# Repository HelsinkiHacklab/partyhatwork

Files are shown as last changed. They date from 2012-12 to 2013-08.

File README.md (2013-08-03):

partyhatwork
============

Mesh network of [party][party1]-[hats][hat1], see http://kirjoitusalusta.fi/hacklab-partyhatwork

[party1]: http://www.youtube.com/watch?v=EIru0xmfsWs
[hat1]: http://www.flickr.com/photos/netlcom/7639700776/in/pool-hlt

## Hardware

  * [rev1](./hardware/board_rev1/)

## Software

  * Reference XMegaduino [sketch](./software/arduino/partyhatwork/)
  * [Instructions](https://github.com/HelsinkiHacklab/XMega-boards/tree/master/software/arduino-xmega) for patching XMegaduino to support our board variant
  * [XBee API wrapper](./software/pc/beehive)
  * [Animation builder](http://helsinkihacklab.github.io/partyhatwork/software/pc/animationbuilder/animationbuilder.html)

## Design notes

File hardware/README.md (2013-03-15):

# Hardware

See directories for details, current board revision is [rev1](./board_rev1/).

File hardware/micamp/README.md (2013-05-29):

# Microphone board

Basically this [sparkfun board][sparkmic] but with better mic and suitably adjusted filter values.

[sparkmic]: https://www.sparkfun.com/products/9964

## BOM

  - http://www.digikey.fi/product-detail/en/CMA-4544PF-W/102-1721-ND/1869981
  - http://www.digikey.fi/product-detail/en/OPA344NA%2F250/OPA344NACT-ND/362263
  - Some standard 0603 size caps & resistors which I will enumerate later

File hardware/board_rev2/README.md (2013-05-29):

# Rev2 board

## TODO

  * Design it, remembering to fix bugs of rev1
  * Decide on on/off solution, heavily leaning towards: [LTC2954](http://www.digikey.fi/product-detail/en/LTC2954CTS8-2%23TRMPBF/LTC2954CTS8-2%23TRMPBFCT-ND/1232682) with [SI4465ADY](http://www.digikey.fi/product-detail/en/SI4465ADY-T1-E3/SI4465ADY-T1-E3CT-ND/1656942)
  * Doublecheck that the 3.3V reg on the XMega board will not throw a hissy fit if  we provide 3.3V from the partyboard (with and without 5V to xmega board provided)
    * In any case [MCP1826T](http://www.digikey.fi/product-detail/en/MCP1826T-3302E%2FDC/MCP1826T-3302E%2FDCCT-ND/1776943) looks like a good choice for regulator (very low drop even at high current) and decent price.
  * Consider MCP73837 as alternative LiPo charger
    * See http://ww1.microchip.com/downloads/en/AppNotes/01149c.pdf
  * Consider adding a [microphone](../micamp/) (for sound-sensitive stuff)
    * or at least a standard header for connecting that board...

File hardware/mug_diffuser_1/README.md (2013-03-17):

# Diffuser for 2 leds based on a plastic mug

## BOM

  * Orthex juomamuki 4dl, EAN: 6411760154911. This particular mug is likely only available in Finland (At least Prisma carries it)
  * Thin aluminium sheet with smooth surface, 155mmx160mm minimum. Bauhaus & K-rauta have these small & thin sheets in various sizes and finishes.

## Instructions

  1. Print the [template](./reflector_template.svg)
  2. Attach it to your alu sheet (glue is ok)
  3. Use tin snips to cut out the two shapes, you can ignore the two small notches
  4. Make a 90-degree bend on the line indicated by the notches. To save yourself the trouble of 
     detaching the template paper, make it so that the paper sides go back-to-back when you have two reflectors.

If you have some sort of CNC that can cut thin metal sheets you can use the [DXF-file](./reflector.dxf).

Some photos: [template][1], [cut & bent][2], [glued][3] & [in use][4]

[1]: https://picasaweb.google.com/lh/photo/nGylbYth7qOaIvtZZEVNvtMTjNZETYmyPJy0liipFm0?feat=directlink
[2]: https://picasaweb.google.com/lh/photo/HIvYXgTCgEQDVCX9EG3fN9MTjNZETYmyPJy0liipFm0?feat=directlink
[3]: https://picasaweb.google.com/lh/photo/DAcRxKpaTQmPHOa6ay1VA9MTjNZETYmyPJy0liipFm0?feat=directlink
[4]: https://picasaweb.google.com/lh/photo/euiXRlEUV-68nEd8NDOWBtMTjNZETYmyPJy0liipFm0?feat=directlink

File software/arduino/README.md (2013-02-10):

# Arduino (well, XMegaduino) software

## partyhatwork

This is the reference implementation of a PartyHatWork node. It implements only the base protocol, if you wish
to extend the protocol or redefine behaviours do not change this sketch but create a new copy. Variants that are deemed
common/good/crazy enough can be added here as separate sketches.

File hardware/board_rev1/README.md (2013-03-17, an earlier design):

# Revision1 board

The current board is designed to be a "shield" to the Xmega32A4U 
breakout board from https://github.com/HelsinkiHacklab/XMega-boards 

Essential pins are pre-connected to modules and drivers, rest of the spare pins (both XMega
and XBee) will be brought out to IDC connectors for further use.

## BOM

  * 1 https://github.com/HelsinkiHacklab/XMega-boards/blob/master/XmegaA4U_v1.jpg (v2 is perfectly fine as well)
    * Flash with [atxmega32a4u_104_PD5.hex](xmegabootloaders/atxmega32a4u_104_PD5.hex) to use PD5 to activate DFU.
      * Convert hex to bin for avrdude: `avr-objcopy -I ihex -O binary atxmega32a4u_104_PD5.hex atxmega32a4u_104_PD5.bin`
      * program with AVRISPmkII: `avrdude -e -c avrisp2 -P usb -p x32a4 -U boot:w:atxmega32a4u_104_PD5.bin`
  * 3 Dual- N-Channel MOSFETs http://fi.rsdelivers.com/product/vishay/si1912edh-t1-e3/mosfet-n-channel-20v-113a-sc-70-6/7103235.aspx
  * 1 XBee (Series 2)
  * 2 1x10 2.0mm female header (for XBee) http://fi.rsdelivers.com/product/harwin/m22-7131042/10w-sil-vertical-pcb-skt/6058796.aspx | http://www.digikey.fi/product-detail/en/M22-7131042/952-1354-5-ND/2264335?cur=USD
  * 2 1x16 2.54mm female header (for XMega) http://fi.rsdelivers.com/product/te-connectivity/1-215297-6/16-way-single-row-vertical-gold-skt/5092880.aspx
  * 1 2x3 2.54mm female header (ISP stacking) http://fi.rsdelivers.com/product/rs/w3482106trc/3-way-2-row-top-entry-socket-01in-pitch/2518216.aspx
  * 1 1x3 2.54mm female header (XMega power connector stacking) http://fi.rsdelivers.com/product/rs/w3481103trc/3way-1-row-top-entry-socket-254mm-pitch/2518187.aspx
  * 1 SOT-223 packaged LDO 3.3V regulator (optional but high-powered one is recommended). **Doublecheck the pinout**: this one is GND-Vout-Vin (LM1117 pinout).
    * This looks like a good choice: http://www.digikey.fi/product-detail/en/ADP3338AKCZ-3.3RL7/ADP3338AKCZ-3.3RL7CT-ND/820438
  * 1 MCP73831T LiPo charge controller http://fi.rsdelivers.com/product/microchip/mcp73831t-2dci-ot/charge-controller-li-ion-li-pol/7240599.aspx
  * 1 JST battery connector http://fi.rsdelivers.com/product/jst/s2b-ph-sm4-tblfsn/ph-smt-side-entry-shroud-header-2-way/6881353.aspx | http://www.digikey.fi/product-detail/en/S2B-PH-SM4-TB%28LF%29%28SN%29/455-1749-1-ND/926846?cur=USD
  * 1 LiPo battery with JST-connector https://www.sparkfun.com/products/8483 or https://www.sparkfun.com/products/8484
  * 1 2x6 2.54mm pin header -right angle
  * 2 2x8 2.54mm pin header -right angle (the other one can alternatively be straight)
  * 2 0805 4.7uF SMD caps
  * 1 0603 SMD led (charge indicator)
  * 1 0603 300r SMD resistor (for charge indicator, adjust value for your LED)
  * 1 0603 2.8k SMD resistor
  * 1 0603 10k SMD resistor
  * 1 0603 50k SMD resistor
  * 1 0603 100k SMD resistor
  * 6 0805 SMD resistors, values based on your desired LED currents
  * 1 0603 0.1uF SMD cap
  * 1 1210 SMD cap (size for your LEDs), 0805 cap should still be solderable too

## Bugs

  * No on/off control for battery power (apart from disconnecting alltotger)
  * without the "optional" regulator battery cannot power the XMega board
    (you could also jumper VBAT to VUSB but that will cause trouble when you connect the USB cable)
  * The 3.3V regulator has weird pinout (whyever eagle has more parts with that one than with the logical and actually more easily available one beats me)
  * The LiPo charge current control resistor pads form a square, making it easy to accidentally place resistors in wrong orientation.

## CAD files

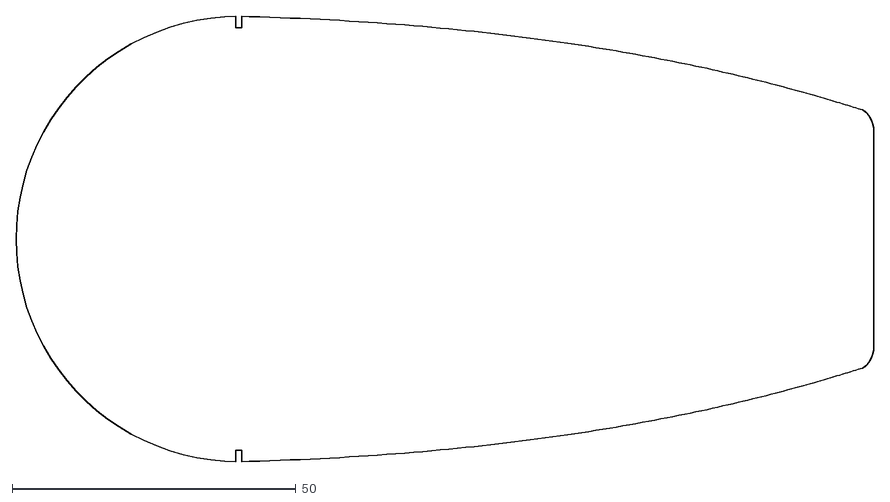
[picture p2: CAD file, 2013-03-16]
hardware/mug_diffuser_1/reflector.dxf
151.2 x 78.5

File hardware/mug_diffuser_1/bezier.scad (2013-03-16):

//=====================================
// This is public Domain Code
// Contributed by: William A Adams
//
// This is from http://www.thingiverse.com/thing:8454
// See also: http://williamaadams.wordpress.com/2011/05/12/mr-bezier-goes-to-openscad/
//=====================================
joinfactor = 0.125;

gSteps = 100;
gHeight = 4;

//======================================
// Demos
//======================================
//BezCubicFilletColored( [[0, 15],[5,5],[10,5],[15,15]], [7.5,12], gSteps, gHeight, 
//	[[1,0,0],[1,1,0],[0,1,1],[0,0,1]]);
//BezCubicFilletColored( [[0, 15],[5,5],[10,5],[15,15]], [7.5,18], gSteps, gHeight, 
//	[[1,0,0],[0,1,0],[0,1,0],[0,0,1]]);
//DrawCubicControlPoints([[0, 15],[5,5],[10,5],[15,15]], [7.5,18], gHeight, $fn=12);

//BezCubicFillet( [[0, 5],[5,15],[10,3],[15,10]], [7.5,0], gSteps, gHeight);
//DrawCubicControlPoints( [[0, 5],[5,15],[10,3],[15,10]], [7.5,0], gHeight, $fn=12);

//BezCubicRibbon([[0,15],[6,13],[3,5],[15,0]], [[0,13],[6,11],[3,2],[13,0]]);

//=======================================
// Functions
// These are the 4 blending functions for a cubic bezier curve
//=======================================
// Bernstein Polynomials
function BEZ03(u) = pow((1-u), 3);
function BEZ13(u) = 3*u*(pow((1-u),2));
function BEZ23(u) = 3*(pow(u,2))*(1-u);
function BEZ33(u) = pow(u,3);

// Calculate a singe point along a cubic bezier curve
function PointOnBezCubic2D(p0, p1, p2, p3, u) = [
	BEZ03(u)*p0[0]+BEZ13(u)*p1[0]+BEZ23(u)*p2[0]+BEZ33(u)*p3[0],
	BEZ03(u)*p0[1]+BEZ13(u)*p1[1]+BEZ23(u)*p2[1]+BEZ33(u)*p3[1]];

function PointOnBezCubic3D(p0, p1, p2, p3, u) = [
	BEZ03(u)*p0[0]+BEZ13(u)*p1[0]+BEZ23(u)*p2[0]+BEZ33(u)*p3[0],
	BEZ03(u)*p0[1]+BEZ13(u)*p1[1]+BEZ23(u)*p2[1]+BEZ33(u)*p3[1],
	BEZ03(u)*p0[2]+BEZ13(u)*p1[2]+BEZ23(u)*p2[2]+BEZ33(u)*p3[2]];

//=======================================
// Modules
//=======================================
// This function will extrude a bezier solid from a bezier curve
// It is a straight up prism
// c - ControlPoints
//
module BezCubicFillet(c, focalPoint, steps=gSteps, height=gHeight)
{
	for(step = [steps:1])
	{
		linear_extrude(height = height, convexity = 10) 
		polygon(
			points=[
				focalPoint,
				PointOnBezCubic2D(c[0], c[1], c[2],c[3], step/steps),
				PointOnBezCubic2D(c[0], c[1], c[2],c[3], (step-1)/steps)],
			paths=[[0,1,2,0]]
		);
	}
}

module BezCubicFilletColored(c, focalPoint, steps=gSteps, height=gHeight, colors)
{
	for(step = [steps:1])
	{
		color(PointOnBezCubic3D(colors[0], colors[1], colors[2], colors[3], step/steps))
		linear_extrude(height = height, convexity = 10) 
		polygon(
			points=[
				focalPoint,
				PointOnBezCubic2D(c[0], c[1], c[2],c[3], step/steps),
				PointOnBezCubic2D(c[0], c[1], c[2],c[3], (step-1)/steps)],
			paths=[[0,1,2,0]]
		);
	}
}


module BezCubicRibbon(c1, c2, steps=gSteps, height=gHeight, colors=[[1,0,0],[1,1,0],[0,1,1],[0,0,1]])
{
	for (step=[0:steps-1])
	{
		color(PointOnBezCubic3D(colors[0], colors[1], colors[2], colors[3], step/steps))
		linear_extrude(height = height, convexity = 10) 
		polygon(
			points=[
				PointOnBezCubic2D(c1[0], c1[1], c1[2],c1[3], step/steps),
				PointOnBezCubic2D(c2[0], c2[1], c2[2],c2[3], (step)/steps),
				PointOnBezCubic2D(c2[0], c2[1], c2[2],c2[3], (step+1)/steps),
				PointOnBezCubic2D(c1[0], c1[1], c1[2],c1[3], (step+1)/steps)],
			paths=[[0,1,2,3]]
		);

	}
}

//==============================================
// Test functions
//
// These test functions help demonstrate that the core blending
// functions actually work correctly.
//==============================================
//PlotBEZ0(100);
//PlotBEZ1(100);
//PlotBEZ2(100);
//PlotBEZ3(100);
//PlotBez4Blending();

module DrawCubicControlPoints(c, focalPoint, height)
{
	// Draw control points
	// Start point
	translate(c[0])
	color([1,0,0])
	cylinder(r=0.5, h=height+joinfactor);

	// Controll point 1
	translate(c[1])
	color([0,0,0])
	cylinder(r=0.5, h=height+joinfactor);

	// Control point 2
	translate(c[2])
	color([0,0,0])
	cylinder(r=0.5, h=height+joinfactor);

	// End Point
	translate(c[3])
	color([0,0,1])
	cylinder(r=0.5, h=height+joinfactor);


	// Draw the focal point
	translate(focalPoint)
	color([0,1,0])
	cylinder(r=0.5, h=height+joinfactor);
}

module PlotBEZ0(steps)
{
	cubeSize = 1;
	cubeHeight = steps;

	for (step=[0:steps])
	{
		translate([cubeSize*step, 0, 0])
		cube(size=[cubeSize, cubeSize, BEZ03(step/steps)*cubeHeight]);
	}	
}

module PlotBEZ1(steps)
{
	cubeSize = 1;
	cubeHeight = steps;

	for (step=[0:steps])
	{
		translate([cubeSize*step, 0, 0])
		cube(size=[cubeSize, cubeSize, BEZ13(step/steps)*cubeHeight]);
	}	
}

module PlotBEZ2(steps)
{
	cubeSize = 1;
	cubeHeight = steps;

	for (step=[0:steps])
	{
		translate([cubeSize*step, 0, 0])
		cube(size=[cubeSize, cubeSize, BEZ23(step/steps)*cubeHeight]);
	}	
}

module PlotBEZ3(steps)
{
	cubeSize = 1;
	cubeHeight = steps;

	for (step=[0:steps])
	{
		translate([cubeSize*step, 0, 0])
		cube(size=[cubeSize, cubeSize, BEZ33(step/steps)*cubeHeight]);
	}	
}

module PlotBez4Blending()
{
	sizing = 100;

	translate([0, 0, sizing + 10])
	PlotBEZ0(100);

	translate([sizing+10, 0, sizing + 10])
	PlotBEZ1(100);

	translate([0, 0, 0])
	PlotBEZ2(100);

	translate([sizing+10, 0, 0])
	PlotBEZ3(100);
}

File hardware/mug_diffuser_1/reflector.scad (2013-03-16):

// This is from http://www.thingiverse.com/thing:8454
// See also: http://williamaadams.wordpress.com/2011/05/12/mr-bezier-goes-to-openscad/
include <bezier.scad>

measured_points = [
    [0, 79.0/2], // x,y (mug sideways, opening to left, tracking *inside* dimensions)
    [110, 46.0/2],
    [110.0/2, 71.0/2],
    [110.0/4, 75.0/2],
    [110.0/4*3, 60.0/2],
];

/**
 * The fitted control points from curve_fitting.py
 *
    (62, 38), # P1
    (97, 27), # P2
 */
/**
 * This is the main shape of half a mug, lacking the steep curve at the very bottom
 */
module half_mug_maincurve()
{
    // Calculate and cache results, will speed up rendering especially when modifying other parameters.
    render()
    {
        union()
        {
            BezCubicFillet([measured_points[0], [62, 38], [97, 27], measured_points[1] ], [0,0]);
            cube([measured_points[1][0], measured_points[1][1], gHeight], center = false);
        }
    }
}
/**
 * Half a mug
 */
bottomcube_xy = [measured_points[1][0]+2, measured_points[1][1]-4];
module half_mug()
{
    $fn=100;
    // Calculate and cache results, will speed up rendering especially when modifying other parameters.
    render()
    {
        union()
        {
            half_mug_maincurve();
            // Cube indicating full depth
            cube([bottomcube_xy[0], bottomcube_xy[1] , gHeight], center = false);
            // Bezier merging the end of the main curve to the bottom cube
            BezCubicFillet([measured_points[1], [bottomcube_xy[0]-1, bottomcube_xy[1]+3.5], [bottomcube_xy[0]+0, bottomcube_xy[1]+2], bottomcube_xy ], [measured_points[1][0]-6,measured_points[1][1]-6]);
        }
    }
}

//half_mug();

module reflector()
{
    $fn=100;
    difference()
    {
        union()
        {
            // Two mug halves mirrored
            half_mug();
            translate([0,0.5,0])
            {
                mirror([0,1,0])
                {
                    half_mug();
                }
            }
            // The semicircle that will be bent 90degrees to form the bottom of the reflector
            translate([0,0.25,0])
            {
                cylinder(r=measured_points[0][1]-0.25, h=gHeight);
            }
        }
        // Two small notches to indicate the bend-line
        translate([-0.5, measured_points[0][1]-2, -0.5])
        {
            cube([1, 2.5, gHeight+1], center = false);
        }
        translate([-0.5, (-1*measured_points[0][1]), -0.5])
        {
            cube([1, 2.5, gHeight+1], center = false);
        }
    }
}

module reflector_2d()
{
    projection(cut=false)
    {
        reflector();
    }
}

// Output the shape
//reflector();
reflector_2d();

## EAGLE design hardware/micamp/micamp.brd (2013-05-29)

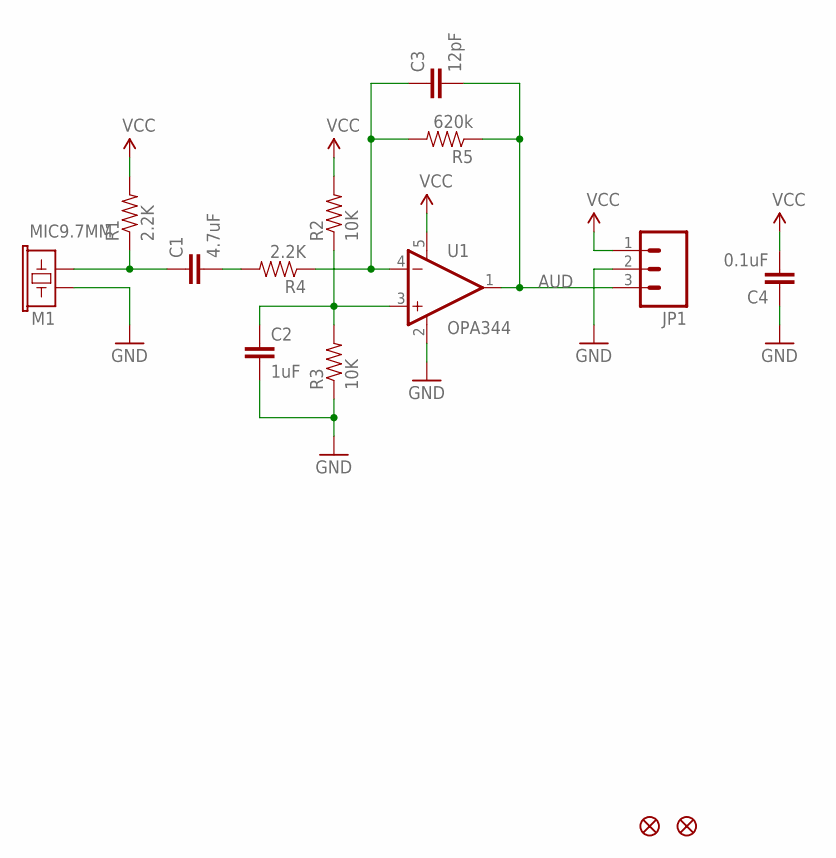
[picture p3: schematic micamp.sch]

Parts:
C1: 4.7uF; 0603-CAP
C2: 1uF; 0603-CAP
C3: 12pF; 0603-CAP
C4: 0.1uF; 0603-CAP
JP1: M03PTH; 1X03
JP2, JP3: FIDUCIAL1X2; FIDUCIAL-1X2
M1: MIC9.7MM; MIC-9.7MM
R1, R4: 2.2K; 0603-RES
R2, R3: 10K; 0603-RES
R5: 620k; 0603-RES
U1: OPA344; SOT23-5

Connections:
AUD: C3.2, JP1.3, R5.1, U1.1 (OUT)
GND: C2.2, C4.1, JP1.2, M1.2, R3.1, U1.2 (V-)
unnamed: C1.1, M1.1, R1.1
unnamed: C3.1, R4.1, R5.2, U1.4 (-IN)
unnamed: C1.2, R4.2
unnamed: C2.1, R2.1, R3.2, U1.3 (+IN)
VCC: C4.2, JP1.1, R1.2, R2.2, U1.5 (V+)

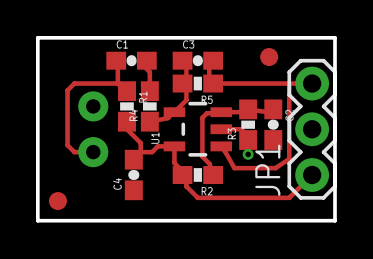
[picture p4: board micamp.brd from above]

Board: 2 copper layers, 16.5 x 10.2 mm, 14 parts (1 on the bottom side), 7 nets.

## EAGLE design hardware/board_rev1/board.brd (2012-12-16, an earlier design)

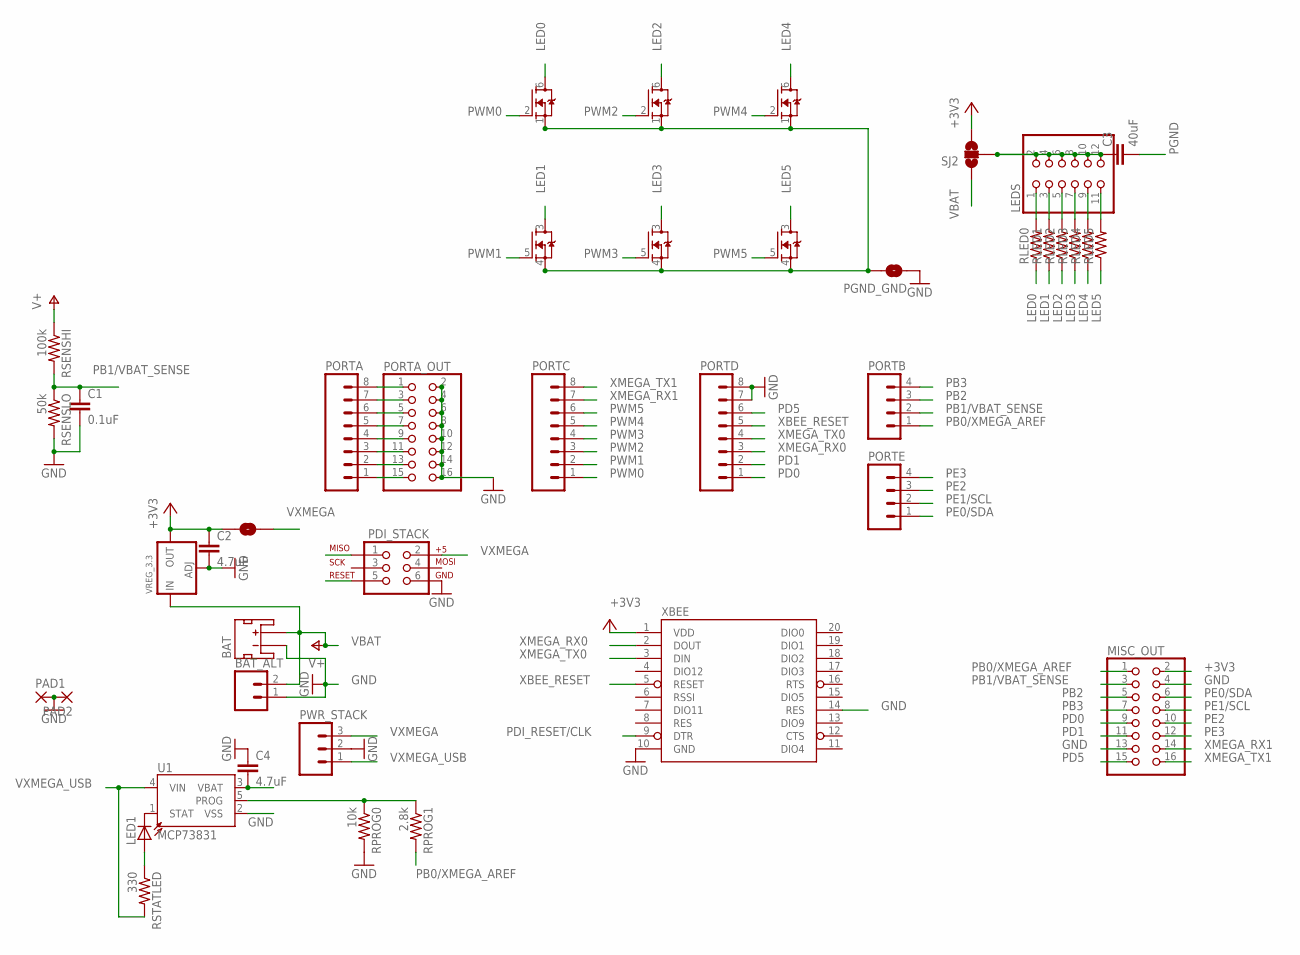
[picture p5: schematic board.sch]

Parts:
+3.3V_VXMEGA: SOLDERJUMPERTRACE; SJ_2S-TRACE
BAT: JST_2MM_MALE; JST-2-SMD
BAT_ALT: M02PTH; 1X02
C1: 0.1uF; C0603K
C2: 4.7uF; C0805K
C3: 40uF; C1210
C4: 4.7uF; C0805
DRV0, DRV1, DRV2: MOSFET-N_DUAL; SOT363
LED1: LEDCHIP-LED0603; CHIP-LED0603
LEDS: PINHD-2X6/90; 2X06/90
MISC_OUT: PINHD-2X8/90; 2X08/90
PAD1, PAD2: 3,81/1,4
PDI_STACK: AVR_SPI_PRG_6NS; 2X3-NS
PGND_GND: SOLDERJUMPERTRACE; SJ_2S-TRACE
PORTA: M081X08; 1X08
PORTA_OUT: PINHD-2X8; 2X08
PORTB: M04PTH; 1X04
PORTC: M081X08; 1X08
PORTD: M081X08; 1X08
PORTE: M04PTH; 1X04
PWR_STACK: M03PTH; 1X03
RLED0, RLED1, RLED2, RLED3, RLED4, RLED5: R-US_R0805; R0805
RPROG0: 10k; R0603
RPROG1: 2.8k; R0603
RSENSHI: 100k; R0603
RSENSLO: 50k; R0603
RSTATLED: 330; R0603
SJ2: SOLDERJUMPER_2WAY-OLDT; SJ_2
U1: MCP73831; SOT23-5
VREG_3.3: LM1117SOT223-WAVE; SOT223-W
XBEE: XBEE-1B2; XBEE-SILK

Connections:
+3V3: +3.3V_VXMEGA.1, C2.1, MISC_OUT.2, SJ2.3, VREG_3.3.2 (OUT), XBEE.1 (VDD)
GND: BAT.1 (-), BAT_ALT.1, C1.2, C2.2, C4.1, MISC_OUT.4, MISC_OUT.13, PAD1.1, PAD2.1, PDI_STACK.6, PGND_GND.1, PORTA_OUT.2, PORTA_OUT.4, PORTA_OUT.6, PORTA_OUT.8, PORTA_OUT.10, PORTA_OUT.12, PORTA_OUT.14, PORTA_OUT.16, PORTD.7, PORTD.8, PWR_STACK.2, RPROG0.2, RSENSLO.2, U1.2 (VSS), VREG_3.3.1 (ADJ), XBEE.10 (GND), XBEE.14 (RES)
LED0: DRV0.6 (D), RLED0.1
LED0R: LEDS.1, RLED0.2
LED1: DRV0.3 (D), RLED1.1
LED1R: LEDS.3, RLED1.2
LED2: DRV1.6 (D), RLED2.1
LED2R: LEDS.5, RLED2.2
LED3: DRV1.3 (D), RLED3.1
LED3R: LEDS.7, RLED3.2
LED4: DRV2.6 (D), RLED4.1
LED4R: LEDS.9, RLED4.2
LED5: DRV2.3 (D), RLED5.1
LED5R: LEDS.11, RLED5.2
unnamed: LED1.C, U1.1 (STAT)
unnamed: LED1.A, RSTATLED.1
PA0: PORTA.1, PORTA_OUT.15
PA1: PORTA.2, PORTA_OUT.13
PA2: PORTA.3, PORTA_OUT.11
PA3: PORTA.4, PORTA_OUT.9
PA4: PORTA.5, PORTA_OUT.7
PA5: PORTA.6, PORTA_OUT.5
PA6: PORTA.7, PORTA_OUT.3
PA7: PORTA.8, PORTA_OUT.1
PB0/XMEGA_AREF: MISC_OUT.1, PORTB.1, RPROG1.2
PB1/VBAT_SENSE: C1.1, MISC_OUT.3, PORTB.2, RSENSHI.2, RSENSLO.1
PB2: MISC_OUT.5, PORTB.3
PB3: MISC_OUT.7, PORTB.4
PD0: MISC_OUT.9, PORTD.1
PD1: MISC_OUT.11, PORTD.2
PD5: MISC_OUT.15, PORTD.6
PDI_DATA: PDI_STACK.1
PDI_RESET/CLK: PDI_STACK.5, XBEE.9 (DTR)
PE0/SDA: MISC_OUT.6, PORTE.1
PE1/SCL: MISC_OUT.8, PORTE.2
PE2: MISC_OUT.10, PORTE.3
PE3: MISC_OUT.12, PORTE.4
PGND: C3.2, DRV0.1 (S), DRV0.4 (S), DRV1.1 (S), DRV1.4 (S), DRV2.1 (S), DRV2.4 (S), PGND_GND.2
PWM0: DRV0.2 (G), PORTC.1
PWM1: DRV0.5 (G), PORTC.2
PWM2: DRV1.2 (G), PORTC.3
PWM3: DRV1.5 (G), PORTC.4
PWM4: DRV2.2 (G), PORTC.5
PWM5: DRV2.5 (G), PORTC.6
RPROG: RPROG0.1, RPROG1.1, U1.5 (PROG)
VBAT: BAT.2 (+), BAT_ALT.2, C4.2, RSENSHI.1, SJ2.1, U1.3 (VBAT), VREG_3.3.3 (IN)
VLED: C3.1, LEDS.2, LEDS.4, LEDS.6, LEDS.8, LEDS.10, LEDS.12, SJ2.2
VXMEGA: +3.3V_VXMEGA.2, PDI_STACK.2, PWR_STACK.3
VXMEGA_USB: PWR_STACK.1, RSTATLED.2, U1.4 (VIN)
XBEE_RESET: PORTD.5, XBEE.5 (RESET)
XMEGA_RX0: PORTD.3, XBEE.2 (DOUT)
XMEGA_RX1: MISC_OUT.14, PORTC.7
XMEGA_TX0: PORTD.4, XBEE.3 (DIN)
XMEGA_TX1: MISC_OUT.16, PORTC.8

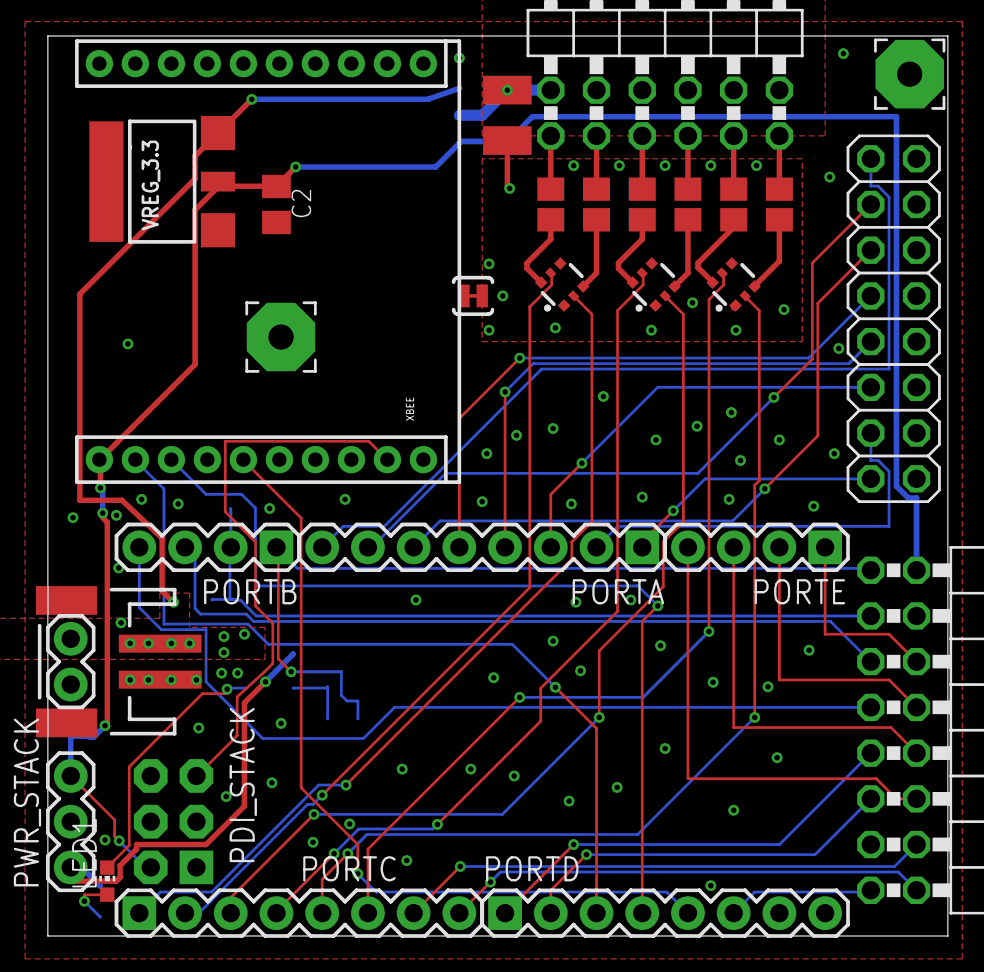
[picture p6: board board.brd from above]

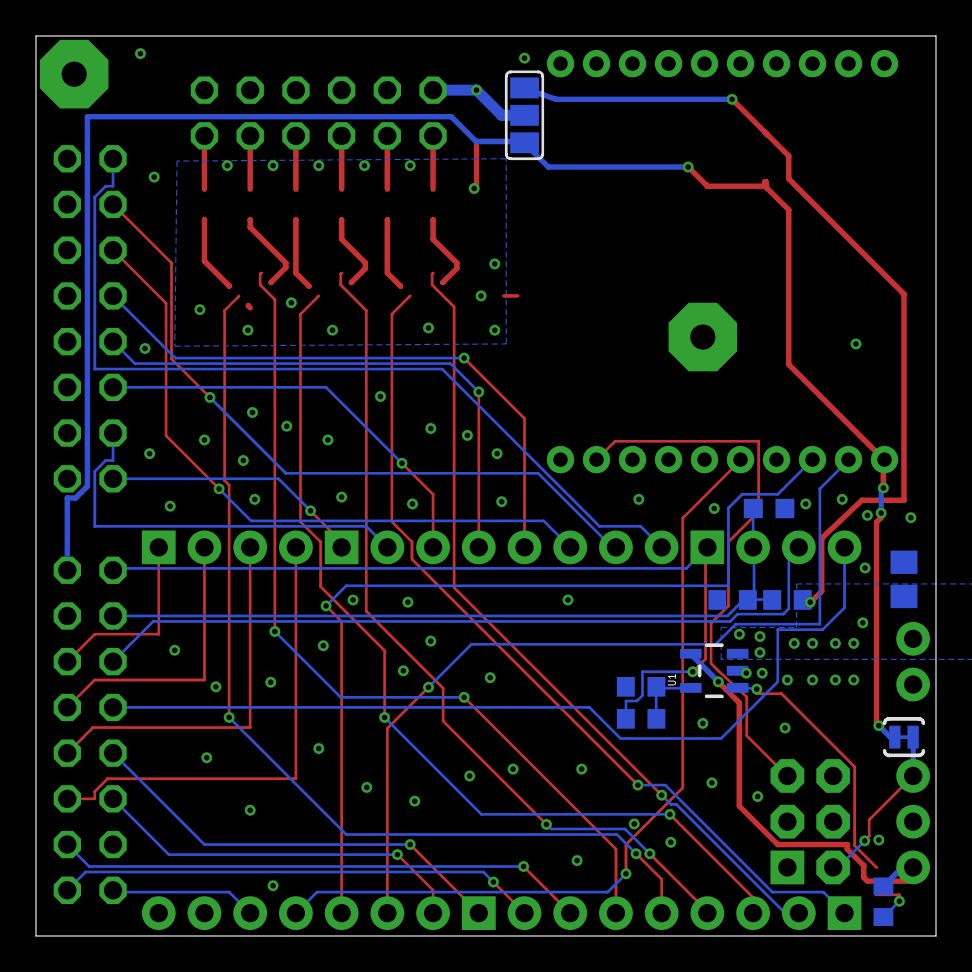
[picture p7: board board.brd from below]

Board: 2 copper layers, 50.0 x 50.0 mm, 39 parts (10 on the bottom side), 53 nets.

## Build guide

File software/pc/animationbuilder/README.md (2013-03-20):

# Helper to make & test animations

Basic idea is to have checkboxes for the mode flags and simple text inputs (R,G,B,Duration) for defining each frame. 
Color picker for the RGB-values a bonus.

A preview mode that will simulate the animation and a button that will generate ready-to-use Arduino code for the animation.

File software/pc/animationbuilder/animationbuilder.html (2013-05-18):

# Partyhatwork animation configurator

## Animation information

Name (valid c++ variable name):

## Active LEDs

Left
Right
Front
Back
Undef 1
Undef 2
Undef 3
Undef 4

### Mode flags

Fading

Add frame Preview Generate code

## Generated code

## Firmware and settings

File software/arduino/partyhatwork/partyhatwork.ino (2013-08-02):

/**
 * Partyhatwork firmware reference implementation, you will need XMega compatible Arduino IDE, see https://github.com/HelsinkiHacklab/XMega-boards/tree/master/software/arduino-xmega
 * 
 * Ge the XBee library from http://code.google.com/p/xbee-arduino/
 * Get the Task library from http://bleaklow.com/files/2010/Task.tar.gz (and fix WProgram.h -> Arduino.h)
 * 
 
   Arduino Pin map

            USB
    0   PE0     GND
    1   PE1     GND
    2   PE2     PD5   29
    3   PE3     PD4   28
    4   PA0     PD3   27
    5   PA1     PD2   26
    6   PA2     PD1   25
    7   PA3     PD0   24
    8   PA4     PC7   23
    9   PA5     PC6   22
   10   PA6     PC5   21
   11   PA7     PC4   20
   12   PB0     PC3   19
   13   PB1     PC2   18
   14   PB2     PC1   17
   15   PB3     PC0   16

From serial_init.cpp: RX/TX
SERIAL_DEFINE(Serial, C, 0); -> PC1/PC3 == 17/19
SERIAL_DEFINE(Serial1, C, 1); -> PC6/PC7 == 22/23
SERIAL_DEFINE(XBEE_SERIAL, D, 0); -> PD2/PD3 == 26/27
//SERIAL_DEFINE(Serial3, D, 1);  This is USB
SERIAL_DEFINE(Serial3, E, 0); -> PE2/PE3 == 2/3

 * 
 */

// If you have EEG module connected, connect it here.
/*
#define BRAIN_SERIAL Serial1
#define BRAIN_POWER_PIN 6
*/
// The high and low parts of the xbee address where to report brain activity, this will be passed to XBeeAddress64-constructor
// TODO: This should be readable (since it's the coordinator) via the XBee API somehow I'm sure...
#define BRAIN_REPORT_TO 0x0013a200, 0x403276df
#define BAT_SENSE_PIN A9
#define HIGH_CURRENT_CHG_PIN 12
#define XBEE_RESET_PIN 28
// This will be HIGH whenever we are *not* sleeping
#define SLEEP_DEBUG_PIN 4
// This will just blink every second
#define BLINKER_PIN 5

// On the partyhat board this is where the XBee is hardwired to
#define XBEE_SERIAL Serial2

// Get this library from http://bleaklow.com/files/2010/Task.tar.gz (and fix WProgram.h -> Arduino.h)
// and read http://bleaklow.com/2010/07/20/a_very_simple_arduino_task_manager.html for background and instructions
#include <Task.h>
#include <TaskScheduler.h>

// Get this library from http://code.google.com/p/xbee-arduino/
#include <XBee.h>
#include "xbee_tasks.h"

// This defines the variable batterymonitor (a task instance) via extern
#include "batterymonitor.h"

// RGB helpers
#include "gammaramp.h"
#include "rgb.h"

// Animations (define some task instances via extern and a bunch of helper functions)
#include "animation_tasks.h"
#include "animations.h"
#include "demo_tasks.h"

#ifdef BRAIN_SERIAL
// Get this from https://github.com/rambo/Arduino-Brain-Library
#include <Brain.h>
// Get this from https://github.com/ratkins/RGBConverter
#include <RGBConverter.h>
#include "brain_tasks.h"
#endif

// This implements the XBee API, first byte is command identifier rest of them are command specific.
void xbee_api_callback(ZBRxResponse rx)
{
    // Check first byte
    switch(rx.getData(0))
    {
        // TODO: Define a sane baseline protocol, for testing we have this dummy RGB setter
        case 0x0:
        {
            setRGB0(rx.getData(1),rx.getData(2),rx.getData(3));
            break;
        }
        case 0x1:
        {
            setRGB1(rx.getData(1),rx.getData(2),rx.getData(3));
            break;
        }
        case 0x2:
        {
            load_nth_animation(rx.getData(1));
            break;
        }
        case 0x3:
        {
#ifdef BRAIN_SERIAL
            eeg_reader.enable(false);
#endif
            anim_switcher.stop_cycle();
            anim_runner.start_animation();
            break;
        }
        case 0x4:
        {
            anim_runner.stop_animation();
            break;
        }
        case 0x5:
        {
#ifdef BRAIN_SERIAL
            eeg_reader.enable(false);
#endif
            anim_switcher.stop_cycle();
            load_nth_animation(rx.getData(1));
            anim_runner.start_animation();
            break;
        }
#ifdef BRAIN_SERIAL
        case 0xF:
        {
            anim_runner.stop_animation();
            anim_switcher.stop_cycle();
            eeg_reader.enable((boolean)rx.getData(1));
            break;
        }
#endif
        case 0x58: // Ascii X
        {
            // Your extended protocol goes here
            break;
        }
    }
}

// An idle task to conserve a little bit of power (it's pretty meaningless as long as we have leds turned on but every little thing counts sometimes and this was easy to do)
#include "sleep_task.h"

#ifdef BLINKER_PIN
#include "blinker.h"
#endif


void setup()
{
    // Initialize the 6 PWM with MOSFETs
    for (byte i=16; i < 23; i++)
    {
        pinMode(i, OUTPUT);
    }
    // XBee reset pin, drive low to reset
    pinMode(XBEE_RESET_PIN, OUTPUT);
    reset_xbee();

    // Initialize the XBee wrapper
    XBEE_SERIAL.begin(57600);
    xbee.begin(XBEE_SERIAL);

#ifdef BRAIN_SERIAL
    BRAIN_SERIAL.begin(57600);
#endif


#ifdef SLEEP_DEBUG_PIN
    pinMode(SLEEP_DEBUG_PIN, OUTPUT);
    // We keep the pin high whenever the sketch is running
    digitalWrite(SLEEP_DEBUG_PIN, HIGH);
#endif
    // Enable high-current charging on the charge controller by default, to be exact we should negotiate for it (or test for dumb charger) first.
    high_current_chg(true);
}

void loop()
{
    // Add the XBee API callback function pointer to the task
    xbeereader.callback = &xbee_api_callback;

#ifdef BLINKER_PIN
    // Initialize a blinker used to make sure the task system is running
    Blinker blinker(BLINKER_PIN, 1000);
    blinker.on_time = 250;
#endif
    
    // Start a "demo mode" (if there is no EEG reader) that will simply cycle the available animations
#ifndef BRAIN_SERIAL
    anim_switcher.start_cycle();
#else
    eeg_reader.enable(true);
#endif

    // Tasks are in priority order, only one task is run per tick, be sure to keep sleeper as last task if you use it.
    Task *tasks[] = { 
        &xbeereader,
        &anim_runner,
        &anim_switcher,
#ifdef BRAIN_SERIAL
        &eeg_anim,
        &eeg_reader,
#endif
#ifdef BLINKER_PIN
        &blinker,
#endif
        &batterymonitor,
        &sleeper
    };
    TaskScheduler sched(tasks, NUM_TASKS(tasks));

    // Run the scheduler - never returns.
    sched.run();
}

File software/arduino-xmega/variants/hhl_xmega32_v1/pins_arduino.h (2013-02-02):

/*
  pins_arduino.h - Pin definition functions for Arduino
  Part of Arduino - http://www.arduino.cc/

  Copyright (c) 2007 David A. Mellis

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
*/

/**
 * Pin map for https://github.com/HelsinkiHacklab/XMega-boards/blob/master/XmegaA4U_v1.brd
 * 
 *

            USB
    1   PE0     GND
    2   PE1     GND
    3   PE2     PD5   30
    4   PE3     PD4   29
    5   PA0     PD3   28
    6   PA1     PD2   27
    7   PA2     PD1   26
    8   PA3     PD0   25
    9   PA4     PC7   24
   10   PA5     PC6   23
   11   PA6     PC5   22
   12   PA7     PC4   21
   13   PB0     PC3   20
   14   PB1     PC2   19
   15   PB2     PC1   18
   16   PB3     PC0   17

Port A&B is ADC, ANALOG0 -> PB3 ANALOG7 -> PA11

USARTS

  Serial = 19 (RX) & 20 (TX)
  Serial1 = 23 (RX) & 24 (TX)
  Serial2 = 27 (RX) & 28 (TX)
  Serial3 = 3 (RX) & 4 (TX)

*/


#ifndef Pins_Arduino_h
#define Pins_Arduino_h

#include <avr/pgmspace.h>


#define REPEAT8(x) x, x, x, x, x, x, x, x
#define BV0TO7 _BV(0), _BV(1), _BV(2), _BV(3), _BV(4), _BV(5), _BV(6), _BV(7)
#define BV7TO0 _BV(7), _BV(6), _BV(5), _BV(4), _BV(3), _BV(2), _BV(1), _BV(0)

#define NUM_DIGITAL_PINS            30
#define NUM_ANALOG_INPUTS           8
#define EXTERNAL_NUM_INTERRUPTS     36 // PORTA to PORTE 3

#define analogInputToDigitalPin(p)  ((p < 6) ? (p) + 22 : -1)
#define digitalPinHasPWM(p)         (((p) >= 2 && (p) <= 6) || ((p) >= 9 && (p)<= 11) || ((p) >= 14 && (p)<= 19))


// TODO: Map correctly
static const uint8_t SS    = 6;
static const uint8_t MOSI  = 11;
static const uint8_t MISO  = 12;
static const uint8_t SCK   = 13;

// TODO: Map correctly
static const uint8_t SDA = 2;
static const uint8_t SCL = 3;
static const uint8_t LED_BUILTIN = 13;

static const uint8_t A0 = 5;
static const uint8_t A1 = 6;
static const uint8_t A2 = 7;
static const uint8_t A3 = 8;
static const uint8_t A4 = 9;
static const uint8_t A5 = 10;
static const uint8_t A6 = 11;
static const uint8_t A7 = 12;
static const uint8_t A8 = 14;
static const uint8_t A9 = 14;
static const uint8_t A10 = 15;
static const uint8_t A11 = 16;

#define Wire xmWireC
#define Wire1 xmWireE

#define SPI_PORT	SPID

#define digitalPinToPCICR(p)    (((p) >= 0 && (p) <= 21) ? (&PCICR) : ((uint8_t *)0))
#define digitalPinToPCICRbit(p) (((p) <= 7) ? 2 : (((p) <= 13) ? 0 : 1))
#define digitalPinToPCMSK(p)    (((p) <= 7) ? (&PCMSK2) : (((p) <= 13) ? (&PCMSK0) : (((p) <= 21) ? (&PCMSK1) : ((uint8_t *)0))))
#define digitalPinToPCMSKbit(p) (((p) <= 7) ? (p) : (((p) <= 13) ? ((p) - 8) : ((p) - 14)))

#ifdef ARDUINO_MAIN

// these arrays map port names (e.g. port B) to the
// appropriate addresses for various functions (e.g. reading
// and writing)
const uint16_t PROGMEM port_to_PGM[] = {
	NOT_A_PORT,
	(uint16_t) &PORTA,
	(uint16_t) &PORTB,
	(uint16_t) &PORTC,
	(uint16_t) &PORTD,
	(uint16_t) &PORTE,
};

const uint8_t PROGMEM digital_pin_to_port_PGM[] = {
    PE,
    PE,
    PE,
    PE,
    PA,
    PA,
    PA,
    PA,
    PA,
    PA,
    PA,
    PA,
    PB,
    PB,
    PB,
    PB,
    PC,
    PC,
    PC,
    PC,
    PC,
    PC,
    PC,
    PC,
    PD,
    PD,
    PD,
    PD,
    PD,
    PD,
};

const uint8_t PROGMEM digital_pin_to_bit_mask_PGM[] = {
		// PIN IN PORT		
		// -------------------------------------------		
		_BV( 0 ), 
		_BV( 1 ),
		_BV( 2 ),
		_BV( 3 ),
		_BV( 0 ),
		_BV( 1 ),
		_BV( 2 ),
		_BV( 3 ),
		_BV( 4 ), 
		_BV( 5 ),
		_BV( 6 ),
		_BV( 7 ),
		_BV( 0 ),
		_BV( 1 ),
		_BV( 2 ), 
		_BV( 3 ),
		_BV( 0 ),
		_BV( 1 ),
		_BV( 2 ),
		_BV( 3 ),
		_BV( 4 ),
		_BV( 5 ), 
		_BV( 6 ), 
		_BV( 7 ),
		_BV( 0 ),
		_BV( 1 ),
		_BV( 2 ),
		_BV( 3 ),
		_BV( 4 ),
		_BV( 5 ),
};

const uint8_t PROGMEM digital_pin_to_timer_PGM[] = {
	// TIMERS		
	// -------------------------------------------		
	TIMER_E0A   	, 
	TIMER_E0B   	, 
	TIMER_E0C   	, 
	TIMER_E0D   	,   // 5
	NOT_ON_TIMER	, 
	NOT_ON_TIMER	, 
	NOT_ON_TIMER	, 
	NOT_ON_TIMER	, 
	NOT_ON_TIMER	, 
	NOT_ON_TIMER	, 
	NOT_ON_TIMER	, 
	NOT_ON_TIMER	, 
	NOT_ON_TIMER	, // 13
	NOT_ON_TIMER	, 
	NOT_ON_TIMER	, 
	NOT_ON_TIMER	, 
	TIMER_C0A   	,  // 17 
	TIMER_C0B   	, 
	TIMER_C0C   	, 
	TIMER_C0D   	, 
	TIMER_C1A   	, 
	TIMER_C1B   	, 
	NOT_ON_TIMER	, 
	NOT_ON_TIMER	, 
	TIMER_D0A       ,  // 25
	TIMER_D0B       , 
	TIMER_D0C       , 
	TIMER_D0D       , 
	TIMER_D1A       , 
	TIMER_D1B       , 
};

const TC0_t* PROGMEM timer_to_tc0_PGM[] = {
	&TCE0   	, 
	&TCE0   	, 
	&TCE0   	, 
	&TCE0   	,   // 5
	NULL	, 
	NULL    , 
	NULL    , 
	NULL    , 
	NULL    , 
	NULL    , 
	NULL    , 
	NULL    , 
	NULL    , // 13
	NULL    , 
	NULL    , 
	NULL    , 
	&TCA0   	,  // 17 
	&TCA0   	, 
	&TCA0   	, 
	&TCA0   	, 
	NULL   	, 
	NULL   	, 
	NULL	, 
	NULL    , 
	&TCD0       ,  // 25
	&TCD0       , 
	&TCD0       , 
	&TCD0       , 
	NULL       , 
	NULL       , 
	};
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

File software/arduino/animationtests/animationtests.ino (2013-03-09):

// Get this library from http://bleaklow.com/files/2010/Task.tar.gz (and fix WProgram.h -> Arduino.h)
// and read http://bleaklow.com/2010/07/20/a_very_simple_arduino_task_manager.html for background and instructions
#include <Task.h>
#include <TaskScheduler.h>

#define SLEEP_DEBUG_PIN A0
#include "sleep_task.h"
SleepTask sleeper;

#include "animation_tasks.h"
#include "animations.h"
AnimationRunner anim_runner;

void load_nth_animation(uint8_t n)
{
    Serial.print(F("load_nth_animation() called with n="));
    Serial.println(n, DEC);
    load_animation_to_buffer(&FIRST_ANIMATION);
    uint8_t i = 0;
    while (true)
    {
        Serial.print(F("i="));
        Serial.println(i, DEC);

        if (i == n)
        {
            anim_runner.set_animation(&animation_buffer);
            break;
        }

        Serial.print(F("Next (address)=0x"));
        Serial.println((uint16_t)&animation_buffer.Next, HEX);

        if (!animation_buffer.Next)
        {
            Serial.print(F("No Next animation defined, aborting at i="));
            Serial.println(i, DEC);
            break;
        }
        load_animation_to_buffer((const Animation*)animation_buffer.Next);
        i++;
    }
    Serial.println(F("load_nth_animation() exiting"));
}

void setup()
{
    Serial.begin(115200);
#ifdef SLEEP_DEBUG_PIN
    pinMode(SLEEP_DEBUG_PIN, OUTPUT);
    // We keep the pin high whenever the sketch is running
    digitalWrite(SLEEP_DEBUG_PIN, HIGH);
#endif
    Serial.println(F("Booted"));
}


void loop()
{
    //load_animation_to_buffer(&foo_anim);
    //anim_runner.set_animation(&foo_anim);
    load_nth_animation(1);
//    load_nth_animation(0);
    // Tasks are in priority order, only one task is run per tick, be sure to keep sleeper as last task if you use it.
    Task *tasks[] = { &anim_runner, &sleeper };
    TaskScheduler sched(tasks, NUM_TASKS(tasks));

    // Run the scheduler - never returns.
    Serial.println(F("Scheduler starting"));
    sched.run();
    Serial.println(F("Scheduler exited (this should NOT happen)"));
}

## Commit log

2012-11-21 started working on the xbee+darlington "shield" for https://raw.github.com/HelsinkiHacklab/XMega-boards/master/Xmega32A4U.jpg
    [board.brd, board.sch]
2012-11-21 minor updates
    [board.brd, board.sch]
2012-11-21 placing a stacking header so we can get reset and 3.3v from the xmega board
    [board.brd, board.sch]
2012-11-21 stack the power connector too and mark out the 50x50mm board area for cheapest chinese boards
    [board.brd, board.sch]
2012-11-21 use the stub portd for rx/tx in case someone is using the rtc xtal on porte
    [board.brd, board.sch]
2012-11-21 reposition the xmega stacking headers, move the xbee breakout to top-left corner
    [board.brd]
2012-11-21 noted the second UART
    [board.brd, board.sch]
2012-11-21 we have 6 HW pwm-channels, so add that many dual-mosfets
    [board.brd, board.sch]
2012-11-21 add general ground pours
    [board.brd]
2012-11-21 added JST battery connector, alternatively 2.54mm pin header can be used
    [board.brd, board.sch]
2012-11-22 placed the led drivers and connectors
    [board.brd, board.sch]
2012-11-22 this header must be 90deg one, otherwise it will not fit under the xbee
    [board.brd, board.sch]
2012-11-22 bigger cap for the leds
    [board.brd, board.sch]
2012-11-22 xbee and xmega share aref
    [board.brd, board.sch]
2012-11-22 connecting rest of the ports
    [board.brd, board.sch]
2012-11-22 adjust the AGND polygon
    [board.brd, board.sch]
2012-11-22 routed the analog signals manualle
    [board.brd]
2012-11-22 smaller agnd polygon
    [board.brd]
2012-11-22 Seeed DRU
    [board.brd]
2012-11-22 autorouter setup
    [board.brd]
2012-11-22 wrong class (and moved the xbee a bit
    [board.brd, board.sch]
2012-11-22 on a second thought, do not put that power pin in the middle of the connector...
    [board.brd, board.sch]
2012-11-22 moved the solder jumper a bit
    [board.brd]
2012-11-22 smaller isolations
    [board.brd]
2012-11-22 put the agnd polygon on top layer too
    [board.brd]
2012-11-22 angle the mosfets in hopes of getting the power signals router better
    [board.brd]
2012-11-22 12mils will have to be enough
    [board.brd, board.sch]
2012-11-22 routed, not very nice or optimal I guess, but it should work
    [board.brd, board.sch]
2012-11-22 mark the jumper resistor values
    [board.brd, board.sch]
2012-11-22 freeroute.net base routing and adjustments + gnd vias on top
    [board.brd]
2012-11-23 get rid of agnd
    [board.brd, board.sch]
2012-11-23 the xbee aref is not used on series2 anyway
    [board.brd, board.sch]
2012-11-23 adjust some vias
    [board.brd]
2012-11-23 version without agnd (but needs no jumper-resistors), the lipo-charger is still missing
    [board.brd]
2012-11-23 ripup in preparation for adding the lipo-charger
    [board.brd]
2012-11-23 placed lipo-charger second R that could be used to enable higher chg current via the UC
    [board.brd, board.sch]
2012-11-23 in wonder what I did there
    [board.brd]
2012-11-23 100mA charge current normally, sink PD5 to GND to make it 500mA
    [board.brd, board.sch]
2012-11-23 lipo-chg in place (I hope)
    [board.brd, board.sch]
2012-11-23 connecting planes
    [board.brd]
2012-11-23 now I need to route that on 3.3v
    [board.brd]
2012-11-23 handle ERC
    [board.brd, board.sch]
2012-11-23 handle DRC
    [board.brd]
2012-11-23 updated readme, added some extra vias to pgnd
    [board.brd]
2012-11-23 remove thermals from PGND
    [board.brd]
2012-11-23 remove thermals from vbat polygon (to get more copper for the lipo chg
    [board.brd]
2012-11-23 hide the airwire, it is connected on the xmega board
    [board.brd]
2012-11-23 forgot to re-route after fixing a signal name
    [board.brd]
2012-11-23 add two large pads that hopefully help with mounting
    [board.brd, board.sch]
2012-11-23 link to correct charge chip
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2012-12-16 invoked labels
    [board.brd, board.sch]
2012-12-16 hanled some DRCs
    [board.sch]
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2013-02-02 typo fix, moar mappings
    [pins_arduino.h]
2013-02-02 typo fixes in mappings
    [pins_arduino.h]
2013-02-02 this probably is the correct way to map channel with the value returned from digital_pin_to_timer_PGM
    [pins_arduino.h]
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2013-02-03 moved the Arduino patches to the repo housing the xmega board designs
2013-02-04 remind about that bug
    [partyhatwork.ino]
2013-02-04 the compile-error is apparently related to the auto-prototyper, see http://code.google.com/p/arduino/issues/detail?id=188
    [partyhatwork.ino]
2013-02-10 run the given RGB values through gamma-correction to get the PWM-value (which is then adjusted based on battery voltage)
    [partyhatwork.ino, rgb.h]
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2013-02-10 reorg, a new HW revision will be needed at some point to address the issues in this one
    [board.brd, board.sch]
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2013-02-13 started working, then realized Iam going to need a serial monitor for debugging (at least...) so I will make a stock arduino sketck for testing this stuff
2013-02-13 stub stock arduino sketch to test just the animations (and idle sleep since that might affect them)
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2013-02-13 the frame pointer passing is somehow borked now, will think about it later
2013-02-13 it almost works, there is probably an off-by-one error somewhere
    [animation_tasks.h, animationtests.ino]
2013-02-13 it works better now but the wait_ms is still wrong
    [animation_tasks.h]
2013-02-14 noted the regulator pinout as a bug
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2013-03-08 hunting for errors in the wrong places...
    [animation_tasks.h, animationtests.ino]
2013-03-09 remove the SRAM frame unpacker, it is not going to be used anymore
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2013-03-09 this actually should not work almost correctly
    [animation_tasks.h]
2013-03-09 comment out the fade interpolation debug, we see it moment later in the leds set method anyway
2013-03-09 this was the wrong way around
    [animation_tasks.h]
2013-03-09 do not try to reset the animation state
    [animation_tasks.h]
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2013-03-15 started work on diffusor reflector plans so did a bit of reorg
    [board.brd, board.sch]
2013-03-16 will be using openscad to model the reflector even if it will be in 2D (maybe I will adjust the bezier lib to skip those linear_extruders soon, or maybe I will just project the "3D" model back to 2D)
    [bezier.scad, reflector.scad]
2013-03-16 use the inner measures and add some comments
    [reflector.scad]
2013-03-16 add reflector bottom
    [reflector.scad]
2013-03-16 add nothes to the bend-line
    [reflector.scad]
2013-03-16 almost ok, but maybe I will try fitting a bezier to this too
    [reflector.scad]
2013-03-16 made the mug bottom
    [reflector.scad]
2013-03-16 added some render-calls
    [reflector.scad]
2013-03-16 exported the 2D projection
    [reflector.dxf, reflector.scad]
2013-03-16 adjusted the dimensions, paper-model testing showed it was a bit too tight previously
    [reflector.dxf, reflector.scad]
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2013-03-23 found the bug in this fade code
    [animation_tasks.h]
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2013-05-29 adjusted schema
    [micamp.brd, micamp.sch]
2013-05-29 switch to 0603 package which is still hand-solderable
    [micamp.brd, micamp.sch]
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2013-06-29 forgot the mode flags from the animation, this now sorta works with the mindband (still getting poor signal from my homemade TGAM breakout and electrodes)
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

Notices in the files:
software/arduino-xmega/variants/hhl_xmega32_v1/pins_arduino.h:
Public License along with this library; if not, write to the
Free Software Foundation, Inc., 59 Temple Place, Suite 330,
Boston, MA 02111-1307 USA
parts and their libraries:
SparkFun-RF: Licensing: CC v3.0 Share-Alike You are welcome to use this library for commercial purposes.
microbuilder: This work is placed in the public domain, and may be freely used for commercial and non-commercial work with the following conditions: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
